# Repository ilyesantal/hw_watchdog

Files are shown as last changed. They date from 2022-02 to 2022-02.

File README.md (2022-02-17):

creator: Antal Ilyes
date: January 2022 - February 2022

This repository was made to contain the development files of a hardware watchdog project for SoftFlex kft.

The hardware watchdog is made of a PCB and a program written in embedded C.

The device is controlled by an ATTyin10 microcontroller. It periodically gets an "alive" tick from the devices connected to it. When an input is driven high, it also turns on a green LED (through an NPN transistor), to visualize it. There is also a red LED indicating the device is powered.

There are two channels that the device can control, as there are only 4 pins on the ATTiny10.

The printed circuit board project can be found under the PCB library. The design was made with KiCAD 6.0

The program works in the following way:

  Initialization: The pins of the microcontroller are set. The corresponding pins to output and to input. The input pins' internal pull-up resistors are also enabled. Then the timer which counts the time passed since the last tick is initialized. Lastly, the interrupts are set up for the input pins.
  
  Timer: There is only one timer in the ATTiny10, so everything has to be done in this. For every trigger (which happens in a frequency that can be set up using the defines), it checks the status of both devices. If the device is inactive, there is nothing to do. If a device is in init status, it is counting the time between the first two ticks. If the device is in active mode, the timer counts the time passed since the last tick.
  
  Input: When an input is driven high, it triggers an interrupt. In the ISR (Interrupt Service Routine) the program determines which input generated the interrupt (as the interrupt vector cannot distinguish which pin did, it triggers when any set pin is triggered), then checks the currenct status of the device corresponding to the pin, and changes the status based on that.
  
  Main loop: If there is a device, which reached the point, where it should be reset, it is indicated to the main loop by the counter which shows that there is a time for which the output should be driven high (which makes the relay to switch off). After it was driven high for the given time, it sets the output back to low.

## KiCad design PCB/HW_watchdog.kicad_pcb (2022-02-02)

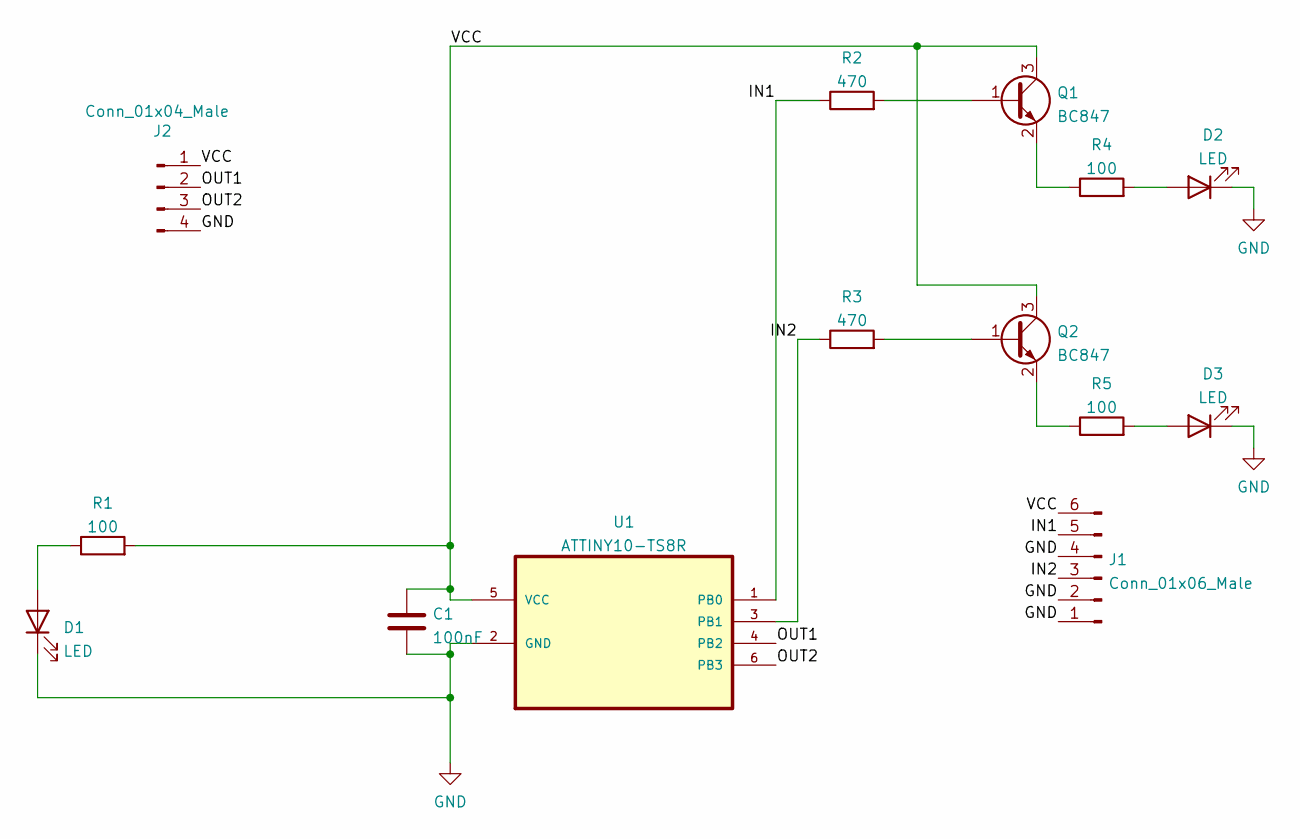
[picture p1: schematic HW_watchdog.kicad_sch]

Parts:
C1: 100nF; D_1206_3216Metric
D1, D2, D3: LED; LED_1206_3216Metric
J1: Conn_01x06_Male; PinHeader_1x06_P2.54mm_Horizontal
J2: Conn_01x04_Male; PinSocket_1x04_P2.54mm_Vertical
Q1, Q2: BC847; SOT-23
R1, R4, R5: 100; R_1206_3216Metric
R2, R3: 470; R_1206_3216Metric
U1: ATTINY10-TS8R; ATTiny10-TS8R; MPN ATTINY10-TS8R

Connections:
/IN1: J1.5, R2.1, U1.1 (PB0)
/IN2: J1.3, R3.1, U1.3 (PB1)
/OUT1: J2.2, U1.4 (PB2)
/OUT2: J2.3, U1.6 (PB3)
/VCC: C1.1, J1.6, J2.1, Q1.3 (C), Q2.3 (C), R1.2, U1.5 (VCC)
GND: C1.2, D1.1 (K), D2.1 (K), D3.1 (K), J1.1, J1.2, J1.4, J2.4, U1.2 (GND)
unnamed: D1.2 (A), R1.1
unnamed: D2.2 (A), R4.2
unnamed: D3.2 (A), R5.2
unnamed: Q1.1 (B), R2.2
unnamed: Q1.2 (E), R4.1
unnamed: Q2.1 (B), R3.2
unnamed: Q2.2 (E), R5.1

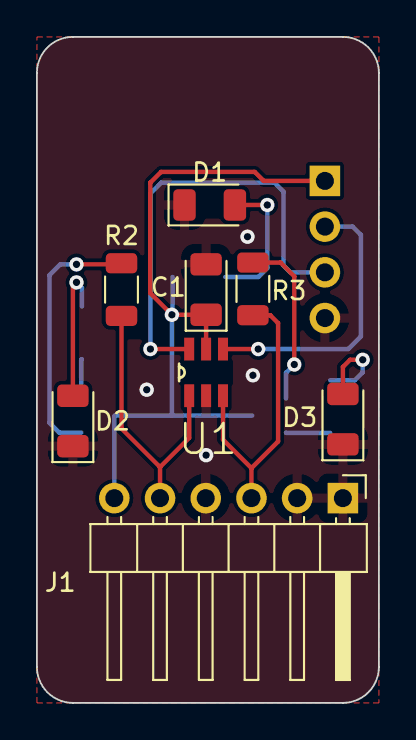
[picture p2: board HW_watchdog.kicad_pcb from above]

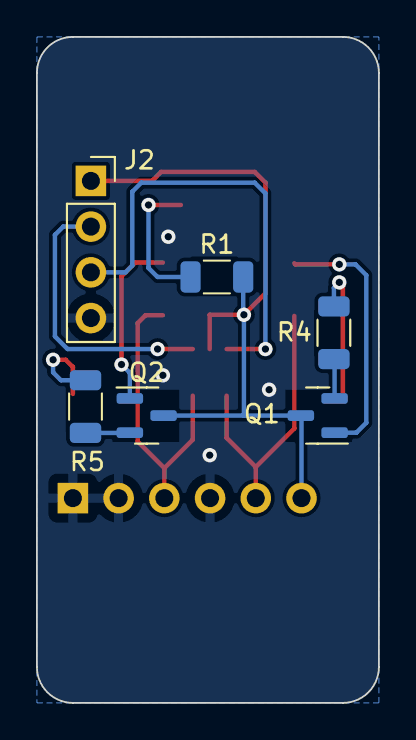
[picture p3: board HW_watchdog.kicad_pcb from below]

Board: 2 copper layers, 19.0 x 37.0 mm, 14 parts (6 on the bottom side), 13 nets.

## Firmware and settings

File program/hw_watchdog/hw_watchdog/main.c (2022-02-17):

/*
 * hw_watchdog.c
 *
 * Created: 2022. 02. 02. 18:30:23
 * Author : Antal Ilyes
 */ 

// waveform types
#define WAVEFORM_GENERATION_MODE_NORMAL 0
#define WAVEFORM_GENERATION_MODE_CTC 4

// clock prescaler types
#define CLOCK_SELECT_BIT_NO_CLK 0
#define CLOCK_SELECT_BIT_NO_PRESCALING 1
#define CLOCK_SELECT_BIT_PRESCALE_8 8
#define CLOCK_SELECT_BIT_PRESCALE_64 64
#define CLOCK_SELECT_BIT_PRESCALE_256 256
#define CLOCK_SELECT_BIT_PRESCALE_1024 1024
#define CLOCK_SELECT_BIT_EXT_T0_FALLING 6
#define CLOCK_SELECT_BIT_EXT_T0_RISING 7

// CPU clock frequency in Hz
#define F_CPU 8000000U

#include <limits.h>
#include <avr/interrupt.h>
#include <util/delay.h>
#include <avr/io.h>

void init_pins();

// defines for the timer initialization
//      timer frequency, in Hz
#define TIMER_FREQ 100
//		prescaler type select
#define CLOCK_SELECT_BIT CLOCK_SELECT_BIT_PRESCALE_1024
//		waveform type select
#define WAVEFORM_GENERATION_MODE WAVEFORM_GENERATION_MODE_CTC
//		calculate the compare register value based on previous parameters
#if ((CLOCK_SELECT_BIT == CLOCK_SELECT_BIT_PRESCALE_1024) || (CLOCK_SELECT_BIT == CLOCK_SELECT_BIT_PRESCALE_256) || (CLOCK_SELECT_BIT == CLOCK_SELECT_BIT_PRESCALE_64) || (CLOCK_SELECT_BIT == CLOCK_SELECT_BIT_PRESCALE_8))
#define OUTPUT_COMPARE_REGISTER_0_A (F_CPU / CLOCK_SELECT_BIT / TIMER_FREQ)
#else
#define OUTPUT_COMPARE_REGISTER_0_A (F_CPU / TIMER_FREQ)
#endif
void init_timer();

void reset_timer();

void init_pcint();

void set_pin(uint8_t pin, uint8_t state);

uint8_t read_pin(uint8_t pin);

// count of iterations while output pulled high
#define HIGH_OUT_COUNTER_MAX 50000
// validation
#if (HIGH_OUT_COUNTER_MAX > INT32_MAX)
#error "overflow error"
#endif

// possible device states
#define DEVICE_STATUS_INACTIVE 0
#define DEVICE_STATUS_INIT 1
#define DEVICE_STATUS_ACTIVE 2

// how many times timer initiated since input
static volatile uint16_t timer_count_0 = 0;	
static volatile uint16_t timer_count_1 = 0;

// status of devices
static volatile uint8_t device_0_status = DEVICE_STATUS_INACTIVE;
static volatile uint8_t device_1_status = DEVICE_STATUS_INACTIVE;

// current counter for devices
static volatile int32_t counter_device_2 = 0;
static volatile int32_t counter_device_3 = 0;

// the rough time between pings
static volatile uint16_t counter_val_0 = 0;
static volatile uint16_t counter_val_1 = 0;

static volatile uint8_t pin_status = 0;

// when TIM0 timer triggers, calling this ISR
ISR(TIM0_COMPA_vect){
	// check device status
	switch(device_0_status){
		// if the device is active
		case DEVICE_STATUS_ACTIVE:
			// increase counter
			timer_count_0++;
			
			//if the counter reaches the maximum value - which is 5 times the input frequency -, set the device to inactive, set the output to high
			if(timer_count_0 > counter_val_0 * 5){
				counter_device_2 = HIGH_OUT_COUNTER_MAX;
				device_0_status = DEVICE_STATUS_INACTIVE;
				timer_count_0 = 0;
			}
			break;
		// if the device is set to init, count the cycles until set to active - which happens when is in init but next input comes
		case DEVICE_STATUS_INIT:
			counter_val_0++;
			break;
		case DEVICE_STATUS_INACTIVE:
			//do nothing
			break;
	}
	
	switch(device_1_status){
		case DEVICE_STATUS_ACTIVE:
			timer_count_1++;
		
			if(timer_count_1 > counter_val_1 * 5){
				counter_device_3 = HIGH_OUT_COUNTER_MAX;
				device_1_status = DEVICE_STATUS_INACTIVE;
				timer_count_1 = 0;
			}
			break;
		case DEVICE_STATUS_INIT:
			counter_val_1++;
			break;
		case DEVICE_STATUS_INACTIVE:
			//do nothing
			break;
	}
}

// when input pins change state, calling this ISR
ISR(PCINT0_vect){
	// PB0 pulled high
	if(PINB & (1 << PINB0)){
		switch(device_0_status){
			// if device was inactive, set it to init, this way the timer starts counting the time between pings, reset the counter value
			case DEVICE_STATUS_INACTIVE:
				counter_val_0 = 0;
				device_0_status = DEVICE_STATUS_INIT;
				break;
			// if was in init, go to active, the timer starts counting
			case DEVICE_STATUS_INIT:
				if(counter_val_0 > 100){
					device_0_status = DEVICE_STATUS_ACTIVE;
				}
				break;
			// if device is active, reset counter, so it doesn't set the out high
			case DEVICE_STATUS_ACTIVE:
				timer_count_0 = 0;
				break;
		}
	}
	// PB1 pulled high
	if(PINB & (1 << PINB1)){
		switch(device_1_status){
			case DEVICE_STATUS_INACTIVE:
				counter_val_1 = 0;
				device_1_status = DEVICE_STATUS_INIT;
				break;
			case DEVICE_STATUS_INIT:
				if(counter_val_1 > 100){
					device_1_status = DEVICE_STATUS_ACTIVE;
				}
				break;
			case DEVICE_STATUS_ACTIVE:
				timer_count_1 = 0;
				break;
		}
	}
}

int main(void)
{
	CCP = 0xD8;						// unlock protected registers
	CLKPSR = 0;						// no divider = 8MHz

	init_pins();
	init_timer();
	init_pcint();
	
	// main loop
    while (1)
    {
		// if output should be set high, set it (only when the value is the max value, so it was just set recently
		if(counter_device_2 > 0){
			if(counter_device_2 == HIGH_OUT_COUNTER_MAX){
				set_pin(PINB2, 1);
			}
			counter_device_2--;
		}
		// if we keeped in high for long enough, set back to low, decrease one more, so it doesn't come to this state again
		else if(counter_device_2 == 0){
			set_pin(PINB2, 0);
			counter_device_2--;
			
		}
	
		if(counter_device_3 > 0){
			if(counter_device_3 == HIGH_OUT_COUNTER_MAX){
				set_pin(PINB3, 1);
			}
			counter_device_3--;
		}
		else if(counter_device_3 == 0){
			set_pin(PINB3, 0);
			counter_device_3--;
		}
		
		_delay_us(100);
    }
}

void set_pin(uint8_t pin, uint8_t state){
	
	if(state){
		PORTB |= (1 << pin);
	}
	else{
		PORTB &= ~(1 << pin);
	}
}

// initialize input and output pins
void init_pins(){
	DDRB |= (1 << PINB2);			// Set the pin pin 2 as output
	DDRB |= (1 << PINB3);			// Set the pin pin 3 as output
	DDRB &= ~(1 << PINB0);			// Set the pin pin 0 as input
	DDRB &= ~(1 << PINB1);			// Set the pin pin 1 as input
	PORTB |= (1 << PINB0);			//activate pull-up resistor for pin 0
	PORTB |= (1 << PINB1);			//activate pull-up resistor for pin 1
	set_pin(PINB2, 0);
	set_pin(PINB3, 0);
}

// initialize timer
void init_timer(){
	
	TCCR0A = 0b00000000;
	
	switch(WAVEFORM_GENERATION_MODE){
		case WAVEFORM_GENERATION_MODE_NORMAL:
			TCCR0B |= 0b00000000;
			break;
		case WAVEFORM_GENERATION_MODE_CTC:
			TCCR0B |= 0b00001000;
			break;
		default:						
			TCCR0B |= 0b00000000;
	}
	
	switch(CLOCK_SELECT_BIT){
		case CLOCK_SELECT_BIT_NO_CLK:
			TCCR0B |= 0b00000000;
			break;
		case CLOCK_SELECT_BIT_NO_PRESCALING:
			TCCR0B |= 0b00000001;
			break;
		case CLOCK_SELECT_BIT_PRESCALE_8:
			TCCR0B |= 0b00000010;
			break;
		case CLOCK_SELECT_BIT_PRESCALE_64:
			TCCR0B |= 0b00000011;
			break;
		case CLOCK_SELECT_BIT_PRESCALE_256:
			TCCR0B |= 0b00000100;
			break;
		case CLOCK_SELECT_BIT_PRESCALE_1024:
			TCCR0B |= 0b00000101;
			break;
		case CLOCK_SELECT_BIT_EXT_T0_FALLING:
			TCCR0B |= 0b00000110;
			break;
		case CLOCK_SELECT_BIT_EXT_T0_RISING:
			TCCR0B |= 0b00000111;
			break;
		default:
			TCCR0B |= 0b00000000;
	}
	
	OCR0AH = OUTPUT_COMPARE_REGISTER_0_A >> 8;
	OCR0AL = OUTPUT_COMPARE_REGISTER_0_A & 0xFF;
		
	TIMSK0 |= (1 << OCIE0A);		// set interrupt for timer
		
	sei();							// enable interrupts
}

void reset_timer(){
	
	cli();
	TCCR0B = 0b00001000;			// deactivate clock
	TCNT0 = 0;						// set clock to 0
	TCCR0B = 0b00001101;			// reactivate clock
	sei();
}

// initialize interrupt for pins
void init_pcint(){
	PCICR |= (1 << PCIE0);
	PCMSK |= (1 << PCINT0);
	PCMSK |= (1 << PCINT1);
}

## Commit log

2022-01-10 pin changed
    [HW_watchdog.kicad_pcb, HW_watchdog.kicad_sch]
2022-02-02 moved pcb to new folder, added software
    [HW_watchdog.kicad_pcb, HW_watchdog.kicad_sch]
